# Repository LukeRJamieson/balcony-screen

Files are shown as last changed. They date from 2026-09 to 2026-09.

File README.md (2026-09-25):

# Balcony privacy screen and plant benches

Five free-standing timber plant benches with lattice privacy screens for a
first-floor townhouse balcony. Nothing is fixed to the building.

**Live 3D model:** https://lukerjamieson.github.io/balcony-screen/

This repository is both the website (`index.html` at the root, served by GitHub
Pages) and the complete build project for the **506 mm deep bench** version.

## What's here

| Path | What it is |
|---|---|
| `index.html` | The approval page with the interactive 3D model. Self-contained; GitHub Pages serves it |
| `Build_Guide.pdf`, `Build_Guide.docx` | Printable build guide: parts list, seven steps with a render at each stage, the 900 mm module, finishing |
| `Cutting_Guide.pdf` | Every stock length drawn to scale, with each piece, kerf, offcuts and a tick box per length |
| `BalconyScreenBench/` | The design model: Fusion 360 script (also plain Python), BOM and cut-list spreadsheet, drawing, cutting-guide generator, build README |
| `stl/` | 3D-printable models of the AC unit, figure, BBQ and bistro set, at real size in mm |
| `application/` | Owners corporation works application attachment (Word and PDF) |
| `docs/github-pages.md` | Notes on hosting and updating the page |

Online slide version of the build guide: https://claude.ai/artifact/VX7RYzKuyGwnUHXprddLsv

## The design at a glance

* Five modules, 600 / 600 / 900 / 600 / 600 mm wide, 3340 mm overall
* 1820 mm high, 506 mm deep, bench top at 500, lower shelf at 130
* 90x45 H3 pine frames bolted with M10 cup heads, 90x22 H3 decking boards and rails,
  Lattice Makers economy lattice, merbau cover strips
* About $966 in materials (see the spreadsheet)

## Regenerating from the model

Everything is generated from one model, so it all stays consistent. Edit `Config`
in `BalconyScreenBench/BalconyScreenBench.py`, then:

    cd BalconyScreenBench
    python BalconyScreenBench.py     # dimensions, cut list, stability check
    python export_bom.py             # rebuild the spreadsheet
    python cutting_guide.py          # redraw ../Cutting_Guide.pdf

Run `BalconyScreenBench.py` as a script inside Fusion 360 for the 3D CAD model.

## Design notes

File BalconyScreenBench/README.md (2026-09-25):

# Balcony lattice screen: 5 independent bench modules

Five free-standing modules (600 / 600 / 900 / 600 / 600). Each module is one Lattice Makers economy
(square grid) lattice panel standing 20 mm off the floor, fixed to the back of its own two-tier plant bench.
**Modules are not fixed to each other, the wall or the floor.** Lattice sits 20 mm off the floor; overall height 1820.

## Files

| File | Purpose |
|---|---|
| `BalconyScreenBench.py` | Fusion 360 script **and** the whole parametric layout, in one file |
| `BalconyScreenBench.manifest` | Required by Fusion; must sit next to the .py |
| `export_bom.py` | Regenerates `Balcony_Screen_BOM.xlsx` from the .py (`--csv` for CSV) |
| `Drawings_elevation_section.png` | Dimensioned elevation + section |

## Running in Fusion 360

1. Unzip so you have a folder named exactly **`BalconyScreenBench`** directly containing
   `BalconyScreenBench.py` and `BalconyScreenBench.manifest`.
2. **Utilities > Add-Ins > Scripts and Add-Ins**, click **+** (or *Script or add-in from device*), pick that folder.
3. Select **BalconyScreenBench** > **Run**. Progress bar > a **new design tab** > summary dialog.

The model has one top-level component per module (`Module 1 - 600 wide` ... `Module 5 - 600 wide`).
Each contains a component per timber part, named to match `Cutting_Guide.pdf` - e.g.
`A 1810 - Screen post, rear bench leg - 90x45 pine length #1` is mark A, 1810 mm long, cut from
stock length #1 on the 90x45 pages - plus its own **Fixings** sub-component
(red M10 bolts, blue 10G x 50, green 10G x 65, purple 10G x 100, black packers), so modules can be moved
or hidden individually.

**If it seems to do nothing:** look at the new tab, then check Text Commands and
`BalconyScreenBench_log.txt` in the script folder. No log file = Fusion never ran the script (folder /
manifest issue). A log that stops part way shows which step failed.

Outside Fusion, `python BalconyScreenBench.py` prints dimensions, the cut list and per-module stability.

## Design (per module)

* Width = its lattice panel; row of 5 is 3340 long with 10 mm gaps, centred on the 3550 wall (105 clear each end).
* 601 deep, bench top 500, lower shelf 130, 258 clear under the bench top, 10 mm clear of the wall.
* Section from the wall out: gap > 42x19 merbau strips > lattice > 90x45 post > bench.
* Two 90x45 posts flush with the module ends (1790 long on 10 mm foot packers). The 900 module also
  gets a short mid rear leg and a third frame so the boards don't span too far.
* Each post/leg forms a cross-frame with a front leg and two bearers, bolted 2 x M10 per lap.
* Three 90x45 rails between the posts (bottom, mid, top at 1820). The lattice is screwed through
  wall-side merbau strips into the posts and rails.
* 90x22 H3 decking cut to module width: 5 top boards, 4 shelf boards.
* Lattice modelled as a square grid (25 mm slats at 95 mm centres - visual only; measure your sheets
  and set `lattice_slat_width` / `lattice_slat_pitch`).

## Stability: read this

Each module stands on its own, so it's only as stable as its own weight (~29 kg for a 600, ~40 kg for
the 900) plus the pots on it. Indicative forward-tipping estimate for wind over the wall, assuming the
total pot load is spread evenly along the row and Bunnings' 20% blockout figure (editable on the Summary sheet):

| Total pots across all 5 modules | 600 modules tip at | 900 module tips at |
|---|---|---|
| None | ~92 km/h | ~90 km/h |
| 150 kg | ~114 km/h | ~115 km/h |
| 300 kg | ~132 km/h | ~135 km/h |

If your sheets are denser than 20% (a 25 mm slat on a 95 mm grid is closer to 45%), set
`lattice_solidity` to suit: at 45% the 150 kg case drops to about 95 km/h.

**People are the bigger risk than wind.** An empty 600 module tips forward with a pull of about
6.5 kg (64 N) at the top of the lattice. A child climbing the bench or pulling on the lattice could
bring it down. Keep the pots on them, and treat them as not climbable.

Rough check only (plants' windage ignored), not an engineering assessment.

## Buying and transport (up to 2.7 m)

`max_carry_length = 2700`, so every length is bought whole and all cutting is done at home:
* 90x45 H3 framing and 90x22 H3 decking: all 2.4 m lengths.
* 42x19 merbau screening is only sold in 2.7 m at Bunnings, so you'll be carrying 2.7 m lengths.
  (Set `max_carry_length = 2400` to have the store make one cut per merbau length instead.)

## Before cutting: measure

1. Actual lattice sheet size, **thickness** (model assumes 12 mm), slat width and grid spacing.
2. Clear length between the side balustrades, and the floor fall along the wall (each module may need
   its own packers to sit level, and neighbouring modules should line up).
3. Whether water pools along the wall. The lattice bottom is 20 mm up (`lattice_z0`); raise it if puddles
   are deeper. Overall height = `lattice_z0` + 1800, and the layout check warns above `max_height` (2000).

## Build sequence (repeat for each module)

1. Cut per the **Cutting Plan** sheet; brush cut ends of H3 pine (especially post tops) with end-grain preservative.
2. Build the cross-frames flat, bearers inside the posts. Clamp square, drill 11 mm, bolt.
3. Stand the frames on foot packers at the module width, screw the rear top board first to lock
   spacing, then the other top and shelf boards.
4. Fit the lattice rails with straight 10G x 100 screws (no angled screws anywhere):
   * **Bottom and mid rails** sit on the shelf and bench-top bearers; screw straight down through the
     rail into the bearer at each end.
   * **Top rail**: screw straight through each end post from the module's outside face into the rail end.
   * **900 module bottom rail** is two pieces either side of the mid rear leg. Fit the left piece first and
     screw through the mid leg from its right-hand face into the rail end, *then* fit the right piece,
     which sits on the mid bearer and the right-hand bearer.
   * Use the **Drilling** sheet for exact screw positions; they're placed to miss the frame bolts.
5. Lay the module on its front (bench side down), place the lattice on the posts, fix the vertical
   merbau strips then the horizontals. Pre-drill and countersink all merbau.
6. Stand it up and carry it out. Each module fits through a standard door (the 900 goes through on
   its 506 mm depth). Place 10 mm off the wall, 10 mm from its neighbour, level with packers.

## Notes

* Merbau with galvanised screws can leave dark tannin stains; stainless 10G screws avoid that.
* M10 x 120 bolts protrude ~15 mm past the nut on the 90 mm laps (M10 x 100 is too short).
* Bolt patterns are mirrored on each module's right-hand frames so cup heads on neighbouring modules
  never line up across the 10 mm gap. The model also checks that no two fixings collide.
* The modular version costs more than a single shared-post unit (10 posts and 88 bolts instead of 6 and 56).

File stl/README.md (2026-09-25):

# 3D-printable models

Five STL files, built from the same geometry as the approval page's 3D model.
They are at **real-world size in millimetres** (Z up, flat on the bed, centred),
so scale them in your slicer. Each is a single watertight solid.

| File | Size (L x W x H) | Notes |
|---|---|---|
| `AC_outdoor_unit.stl` | 857 x 333 x 703 mm | Fan guard rings are 14 mm thick at full size |
| `Manikin_1750mm.stl` | 550 x 293 x 1739 mm | Actually 1739 mm tall, as rendered on the page. Rounded feet: use a brim |
| `Weber_kettle_BBQ.stl` | 479 x 479 x 929 mm | Legs are 28 mm diameter at full size; use a brim |
| `Bistro_chair.stl` | 630 x 630 x 835 mm | Print twice |
| `Bistro_table.stl` | 400 x 400 x 380 mm | Prints best upside down on its top |

Small changes made so each prints as one piece (overall sizes unchanged):
the AC fan cowl is a solid ring joined to the guard; the BBQ bowl and lid are
one body, its legs reach the bowl, and the ash catcher and lid handle are
nudged into the body.

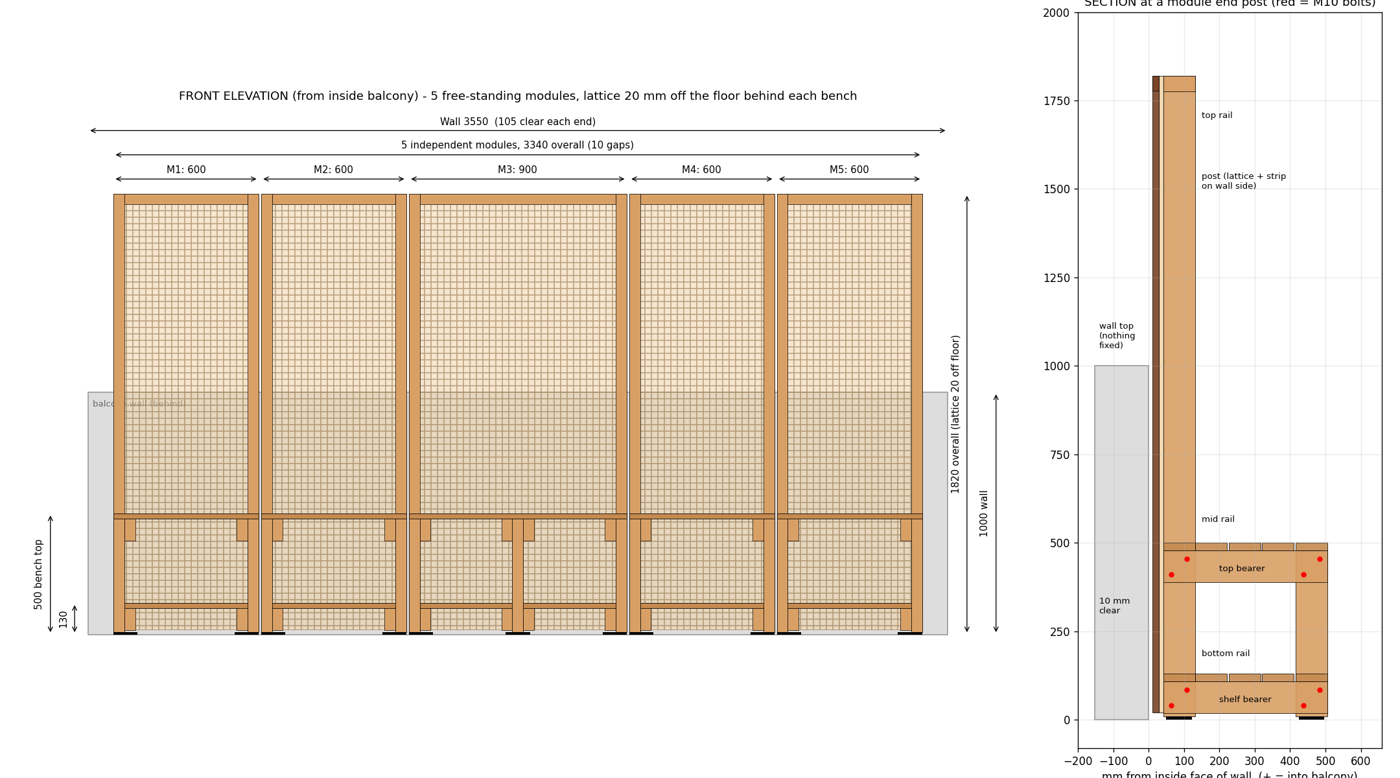
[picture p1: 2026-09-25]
BalconyScreenBench/Drawings_elevation_section.png

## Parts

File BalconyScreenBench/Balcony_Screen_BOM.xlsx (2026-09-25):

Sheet: Summary
Balcony lattice screen - 5 independent bench modules - BOM & cut list
Generated from BalconyScreenBench.py - re-run export_bom.py after changing Config.
Key dimensions (mm)
Wall length (measured) | 3550 | From Luke's measurement
Wall height (approx.) | 1000 | About 1 m - reference only, nothing is fixed to the wall
Lattice panel layout | 600 / 600 / 900 / 600 / 600 | Symmetrical, joints land on posts
Number of independent modules | 5 | One lattice panel + its own bench each; not fixed together
Gap between modules | 10
Overall length of the row | 3340 | Modules + gaps, centred on the wall
Clearance each end | 105 | Wall length minus unit length, halved
Bench top height | 500
Lattice bottom above floor | 20 | Lifted clear of standing water, behind the bench
Maximum height allowed | 2000 | Nothing projects above this
Lower shelf height | 130
Clear height under bench top | 258 | Max pot height on lower shelf
Bench depth from wall | 506
Overall height (top of screen) | 1820
Screen height above wall top | 820
Lattice thickness (assumed) | 12 | NOT listed by Bunnings - measure a sheet
Inputs
Spare allowance - boxed screws | 10% | Extra screws for split/lost ones
Spare allowance - loose items | 5% | Bolts, washers, packers
Estimated total (AUD, inc GST) | $965.94 | Sum of BOM line totals
Stability - INDICATIVE ONLY (not an engineering check)
Total pot + soil load, all modules (kg) | 150 | Edit: weigh or estimate your pots
Module checked | M1 (600 wide) | Least stable module (modules are independent)
Module share of pots (by width) | 18.2% | Assumes pots spread evenly along the row
Unit self weight (kg) | 25.9 | This module only, from timber volumes and densities
Self-weight lever arm to front edge (m) | 0.324 | Horizontal distance, centre of mass to front of legs
Pot lever arm to front edge (m) | 0.188 | Pots assumed centred on bench top
Drag coefficient on solid area | 1.2 | Edit if you have better data
Solid frontal area above wall top (m2) | 0.171 | 20% of lattice + cover strips, above the wall (wall shelters the rest)
Height of wind load centroid (m) | 1.449 | Above deck
Resisting moment (N.m) | 132.6151116 | (self weight x lever + pot share x lever) x 9.81
Estimated tipping gust (km/h) | 98.15230707 | Wind over the wall pushing the unit into the balcony
Legend
Blue text on yellow = input you can edit
Prices: Bunnings online price checked 16 Sep 2026. Packs (e.g. 25-pack bolts) are often cheaper per unit.

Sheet: BOM
Item | Category | Bunnings product | Buy unit | Qty needed | Pack size | Qty to buy | Unit price (AUD) | Line total (AUD) | Link | Notes | Alt supplier | Alt buy unit | Alt pack size | Alt qty to buy | Alt unit price (AUD) | Alt line total (AUD) | Alt link | Cheaper by (AUD)
1 | Timber | 90 x 45mm Outdoor Framing H3 Treated Pine (MGP10) | 2.4 m length | 17 | 1 | 17 | $18.50 | $314.50 | Bunnings (https://www.bunnings.com.au/90-x-45mm-outdoor-framing-mgp10-h3-treated-pine-1-8m-2-4m_p8032172) | Posts, bench frames, lattice rails (bottom / mid / top). Trade counter - price on application. Quote the whole timber list at once | Bowens Croydon / Mount Evelyn, Bayswater Mitre 10 | 2.4 m length |  |  |  |  | Supplier (https://bowens.com.au/stores/croydon)
2 | Timber | 90 x 22mm Decking H3 Treated Pine | 2.4 m length | 14 | 1 | 14 | $9.58 | $134.12 | Bunnings (https://www.bunnings.com.au/90-x-22mm-decking-h3-treated-pine-2-4m_p8032583) | Per module: 5 top + 4 shelf boards cut to module width. Trade counter - price on application | Bowens Croydon / Mount Evelyn, Bayswater Mitre 10 | 2.4 m length |  |  |  |  | Supplier (https://bowens.com.au/stores/croydon)
3 | Timber | SpecRite 42 x 19mm Merbau Pre-Oiled Solid Screening | 2.7 m length | 10 | 1 | 10 | $9.00 | $90.00 | Bunnings (https://www.bunnings.com.au/products/building-hardware/fencing/timber-fencing) | Cover strips on the wall side (hardwood - pre-drill). Only sold in 2.7 m: ask Bunnings to cut each length at the position on the Cutting Plan sheet. Merbau screening lengths vary by merchant - check stocked lengths | Bowens Croydon / Mount Evelyn, Bayswater Mitre 10 | length |  |  |  |  | Supplier (https://bowens.com.au/stores/croydon)
4 | Lattice | Lattice Makers 1800 x 600mm Economy Lattice | sheet | 4 | 1 | 4 | $19.99 | $79.96 | Bunnings (https://www.bunnings.com.au/lattice-makers-1800-x-600mm-economy-lattice_p0920946) | 20% blockout, pine; no cutting needed
5 | Lattice | Lattice Makers 1800 x 900mm Economy Lattice | sheet | 1 | 1 | 1 | $27.89 | $27.89 | Bunnings (https://www.bunnings.com.au/lattice-makers-1800-x-900mm-economy-lattice_p0920950) | 20% blockout, pine; no cutting needed
6 | Fixings | ZENITH M10 x 120mm Hot Dip Galvanised Cup Head Bolts & Nuts - Each | each | 80 | 1 | 84 | $1.74 | $146.16 | Bunnings (https://www.bunnings.com.au/zenith-m10-x-120mm-hot-dip-galvanised-cup-head-bolts-nuts-each_p2443953) | Frame lap joints, 2 per joint. Far cheaper by the box - see alt supply. Also Scrooz: trade box of 25 at $25.39 ($1.02 ea), free shipping over $99 | The Fastener Factory (Clayton / online) | box of 50 | 50 | 2 | $38.09 | $76.18 | Supplier (https://www.thefastenerfactory.com.au/m10-x-120mm-50pc-cup-head-bolt-nut-hot-dip-galvanised-as1390-class-4-6-uts) | $69.98
7 | Fixings | ZENITH M10 x 150mm Hot Dip Galvanised Cup Head Bolts & Nuts - Each | each | 8 | 1 | 9 | $1.94 | $17.46 | Bunnings (https://www.bunnings.com.au/zenith-m10-x-150mm-hot-dip-galvanised-cup-head-bolts-nuts-each_p2443987) | The 900 module's middle frame only: four joints of 45 + 45 + 45
8 | Fixings | ZENITH M10 Hot Dip Galvanised Flat Round Washers - Each | each | 88 | 1 | 93 | $0.30 | $27.90 | Bunnings (https://www.bunnings.com.au/zenith-m10-hot-dip-galvanised-flat-round-washers-each_p2442070) | One under each nut, both bolt lengths. One box covers the job several times over; cheaper than 93 loose | The Fastener Factory (Clayton / online) | box of 500 | 500 | 1 | $22.87 | $22.87 | Supplier (https://www.thefastenerfactory.com.au/m10-galvanised-flat-washers-10mm-x-22-5-x-2-0-500pc) | $5.03
9 | Fixings | Zenith 10-8 x 50mm Galvanised Countersunk Rib Head Timber Screws - 50 Pack | pack | 192 | 50 | 5 | $8.79 | $43.95 | Bunnings (https://www.bunnings.com.au/search/products?q=galvanised+timber+screws) | Deck boards to bearers, 2 per board per bearer
10 | Fixings | Zenith 10-8 x 65mm Galvanised Countersunk Rib Head Timber Screws - 50 Pack | pack | 86 | 50 | 2 | $10.90 | $21.80 | Bunnings (https://www.bunnings.com.au/products/building-hardware/fasteners-fixings/screws/treated-pine-screws) | Cover strips through lattice into posts and rails @ ~300 c/c
11 | Fixings | Zenith 10-8 x 100mm Galvanised Countersunk Rib Head Timber Screws - 50 Pack | pack | 64 | 50 | 2 | $14.90 | $29.80 | Bunnings (https://www.bunnings.com.au/zenith-10-8-x-100mm-galvanised-countersunk-rib-head-timber-screws-50-pack_p2420881) | Lattice rails: down into bearers or through the end posts, 2 per rail end. Buy the 50-pack, not 8-packs
12 | Fixings | Titan 10 x 72 x 100mm Black Shim Packing | each | 22 | 1 | 24 | $1.35 | $32.40 | Bunnings (https://www.bunnings.com.au/products/building-hardware/fasteners-fixings) | Feet under every leg (confirm sold each). Ask for plastic packers by the bag rather than singly | Trade counter (Bowens / Mitre 10) | bag |  |  |  |  | Supplier (https://bowens.com.au/stores/croydon)
 |  |  |  |  |  |  | TOTAL | $965.94 |  |  |  |  |  | TOTAL, cheaper option per row |  | $890.93 | Saving | $75.01
 |  |  |  |  |  |  |  |  |  |  | Rows with an alt price are priced both ways; blank alt prices are trade counters that quote on request.
 |  | Not included: exterior oil/stain, drill bits (11 mm auger, 3.5 mm pilot, countersink), and any owners corporation fees.

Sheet: Cut List
Mark | Description | Material | Section | Cut length (mm) | Qty | Total length (m) | Part IDs
A | Screen post / rear bench leg | 90 x 45mm Outdoor Framing H3 Treated Pine (MGP10) | 90x45 | 1810 | 10 | 18.10 | M1-POST-1 M1-POST-2 M2-POST-1 M2-POST-2 M3-POST-1 M3-POST-2 M4-POST-1 M4-POST-2 M5-POST-1 M5-POST-2
B | Lattice rail (top) | 90 x 45mm Outdoor Framing H3 Treated Pine (MGP10) | 90x45 | 810 | 1 | 0.81 | M3-RAILTOP-4
C | Lattice rail (top) | 90 x 45mm Outdoor Framing H3 Treated Pine (MGP10) | 90x45 | 510 | 4 | 2.04 | M1-RAILTOP-3 M2-RAILTOP-3 M4-RAILTOP-3 M5-RAILTOP-3
D | Front bench leg; Rear bench leg (mid frame) | 90 x 45mm Outdoor Framing H3 Treated Pine (MGP10) | 90x45 | 468 | 12 | 5.62 | M1-FLEG-1 M1-FLEG-2 M2-FLEG-1 M2-FLEG-2 M3-FLEG-1 M3-RLEG-1 M3-FLEG-2 M3-FLEG-3 M4-FLEG-1 M4-FLEG-2 M5-FLEG-1 M5-FLEG-2
E | Bench top bearer; Lower shelf bearer | 90 x 45mm Outdoor Framing H3 Treated Pine (MGP10) | 90x45 | 465 | 24 | 11.16 | M1-TBEAR-1 M1-LBEAR-1 M1-TBEAR-2 M1-LBEAR-2 M2-TBEAR-1 M2-LBEAR-1 M2-TBEAR-2 M2-LBEAR-2 M3-TBEAR-1 M3-LBEAR-1 M3-TBEAR-2 M3-LBEAR-2 M3-TBEAR-2B M3-LBEAR-2B M3-TBEAR-3 M3-LBEAR-3 M4-TBEAR-1 M4-LBEAR-1 M4-TBEAR-2 M4-LBEAR-2 M5-TBEAR-1 M5-LBEAR-1 M5-TBEAR-2 M5-LBEAR-2
F | Bench top board; Lower shelf board | 90 x 22mm Decking H3 Treated Pine | 90x22 | 900 | 7 | 6.30 | M3-TOP-1 M3-TOP-2 M3-TOP-3 M3-TOP-4 M3-SHELF-1 M3-SHELF-2 M3-SHELF-3
G | Lattice rail (mid) | 90 x 22mm Decking H3 Treated Pine | 90x22 | 810 | 1 | 0.81 | M3-RAILMID-3
H | Bench top board; Lower shelf board | 90 x 22mm Decking H3 Treated Pine | 90x22 | 600 | 28 | 16.80 | M1-TOP-1 M1-TOP-2 M1-TOP-3 M1-TOP-4 M1-SHELF-1 M1-SHELF-2 M1-SHELF-3 M2-TOP-1 M2-TOP-2 M2-TOP-3 M2-TOP-4 M2-SHELF-1 M2-SHELF-2 M2-SHELF-3 M4-TOP-1 M4-TOP-2 M4-TOP-3 M4-TOP-4 M4-SHELF-1 M4-SHELF-2 M4-SHELF-3 M5-TOP-1 M5-TOP-2 M5-TOP-3 M5-TOP-4 M5-SHELF-1 M5-SHELF-2 M5-SHELF-3
I | Lower shelf board; Lattice rail (bot); Lattice rail (mid) | 90 x 22mm Decking H3 Treated Pine | 90x22 | 510 | 12 | 6.12 | M1-SHELF-4a M1-RAILBOT-1 M1-RAILMID-2 M2-SHELF-4a M2-RAILBOT-1 M2-RAILMID-2 M4-SHELF-4a M4-RAILBOT-1 M4-RAILMID-2 M5-SHELF-4a M5-RAILBOT-1 M5-RAILMID-2
J | Lower shelf board; Lattice rail (bot) | 90 x 22mm Decking H3 Treated Pine | 90x22 | 382.5 | 4 | 1.53 | M3-SHELF-4a M3-SHELF-4b M3-RAILBOT-1 M3-RAILBOT-2
K | Vertical cover strip (wall side) | SpecRite 42 x 19mm Merbau Pre-Oiled Solid Screening | 42x19 | 1800 | 10 | 18.00 | M1-VSTRIP-1 M1-VSTRIP-2 M2-VSTRIP-1 M2-VSTRIP-2 M3-VSTRIP-1 M3-VSTRIP-2 M4-VSTRIP-1 M4-VSTRIP-2 M5-VSTRIP-1 M5-VSTRIP-2
L | Horizontal cover strip (top, wall side) | SpecRite 42 x 19mm Merbau Pre-Oiled Solid Screening | 42x19 | 816 | 1 | 0.82 | M3-HSTRIP-TOP
M | Horizontal cover strip (top, wall side) | SpecRite 42 x 19mm Merbau Pre-Oiled Solid Screening | 42x19 | 516 | 4 | 2.06 | M1-HSTRIP-TOP M2-HSTRIP-TOP M4-HSTRIP-TOP M5-HSTRIP-TOP
Lengths are finished sizes. Cut 90x45 and decking square; pre-drill all merbau (hardwood).

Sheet: Cutting Plan
Stock # | Material key | Material | Stock length (mm) | Pieces (mark: length) | No. pieces | Pieces total (mm) | Kerf + trim (mm) | Offcut (mm) | Ask store to cut at (mm from one end)
T90x45-1 | T90x45 | 90 x 45mm Outdoor Framing H3 Treated Pine (MGP10) | 2400 | A: 1810 | C: 510 | 2 | 2320 | 16 | 64
T90x45-2 | T90x45 | 90 x 45mm Outdoor Framing H3 Treated Pine (MGP10) | 2400 | A: 1810 | C: 510 | 2 | 2320 | 16 | 64
T90x45-3 | T90x45 | 90 x 45mm Outdoor Framing H3 Treated Pine (MGP10) | 2400 | A: 1810 | C: 510 | 2 | 2320 | 16 | 64
T90x45-4 | T90x45 | 90 x 45mm Outdoor Framing H3 Treated Pine (MGP10) | 2400 | A: 1810 | C: 510 | 2 | 2320 | 16 | 64
T90x45-5 | T90x45 | 90 x 45mm Outdoor Framing H3 Treated Pine (MGP10) | 2400 | A: 1810 | D: 468 | 2 | 2278 | 16 | 106
T90x45-6 | T90x45 | 90 x 45mm Outdoor Framing H3 Treated Pine (MGP10) | 2400 | A: 1810 | D: 468 | 2 | 2278 | 16 | 106
T90x45-7 | T90x45 | 90 x 45mm Outdoor Framing H3 Treated Pine (MGP10) | 2400 | A: 1810 | D: 468 | 2 | 2278 | 16 | 106
T90x45-8 | T90x45 | 90 x 45mm Outdoor Framing H3 Treated Pine (MGP10) | 2400 | A: 1810 | D: 468 | 2 | 2278 | 16 | 106
T90x45-9 | T90x45 | 90 x 45mm Outdoor Framing H3 Treated Pine (MGP10) | 2400 | A: 1810 | D: 468 | 2 | 2278 | 16 | 106
T90x45-10 | T90x45 | 90 x 45mm Outdoor Framing H3 Treated Pine (MGP10) | 2400 | A: 1810 | D: 468 | 2 | 2278 | 16 | 106
T90x45-11 | T90x45 | 90 x 45mm Outdoor Framing H3 Treated Pine (MGP10) | 2400 | B: 810 | D: 468 | D: 468 | D: 468 | 4 | 2214 | 22 | 164
T90x45-12 | T90x45 | 90 x 45mm Outdoor Framing H3 Treated Pine (MGP10) | 2400 | D: 468 | D: 468 | D: 468 | E: 465 | E: 465 | 5 | 2334 | 25 | 41
T90x45-13 | T90x45 | 90 x 45mm Outdoor Framing H3 Treated Pine (MGP10) | 2400 | E: 465 | E: 465 | E: 465 | E: 465 | E: 465 | 5 | 2325 | 25 | 50
T90x45-14 | T90x45 | 90 x 45mm Outdoor Framing H3 Treated Pine (MGP10) | 2400 | E: 465 | E: 465 | E: 465 | E: 465 | E: 465 | 5 | 2325 | 25 | 50
T90x45-15 | T90x45 | 90 x 45mm Outdoor Framing H3 Treated Pine (MGP10) | 2400 | E: 465 | E: 465 | E: 465 | E: 465 | E: 465 | 5 | 2325 | 25 | 50
T90x45-16 | T90x45 | 90 x 45mm Outdoor Framing H3 Treated Pine (MGP10) | 2400 | E: 465 | E: 465 | E: 465 | E: 465 | E: 465 | 5 | 2325 | 25 | 50
T90x45-17 | T90x45 | 90 x 45mm Outdoor Framing H3 Treated Pine (MGP10) | 2400 | E: 465 | E: 465 | 2 | 930 | 16 | 1454
D90x22-1 | D90x22 | 90 x 22mm Decking H3 Treated Pine | 2400 | F: 900 | F: 900 | I: 510 | 3 | 2310 | 19 | 71
D90x22-2 | D90x22 | 90 x 22mm Decking H3 Treated Pine | 2400 | F: 900 | F: 900 | I: 510 | 3 | 2310 | 19 | 71
D90x22-3 | D90x22 | 90 x 22mm Decking H3 Treated Pine | 2400 | F: 900 | F: 900 | I: 510 | 3 | 2310 | 19 | 71
D90x22-4 | D90x22 | 90 x 22mm Decking H3 Treated Pine | 2400 | F: 900 | G: 810 | H: 600 | 3 | 2310 | 19 | 71
D90x22-5 | D90x22 | 90 x 22mm Decking H3 Treated Pine | 2400 | H: 600 | H: 600 | H: 600 | I: 510 | 4 | 2310 | 22 | 68
D90x22-6 | D90x22 | 90 x 22mm Decking H3 Treated Pine | 2400 | H: 600 | H: 600 | H: 600 | I: 510 | 4 | 2310 | 22 | 68
D90x22-7 | D90x22 | 90 x 22mm Decking H3 Treated Pine | 2400 | H: 600 | H: 600 | H: 600 | I: 510 | 4 | 2310 | 22 | 68
D90x22-8 | D90x22 | 90 x 22mm Decking H3 Treated Pine | 2400 | H: 600 | H: 600 | H: 600 | I: 510 | 4 | 2310 | 22 | 68
D90x22-9 | D90x22 | 90 x 22mm Decking H3 Treated Pine | 2400 | H: 600 | H: 600 | H: 600 | I: 510 | 4 | 2310 | 22 | 68
D90x22-10 | D90x22 | 90 x 22mm Decking H3 Treated Pine | 2400 | H: 600 | H: 600 | H: 600 | I: 510 | 4 | 2310 | 22 | 68
D90x22-11 | D90x22 | 90 x 22mm Decking H3 Treated Pine | 2400 | H: 600 | H: 600 | H: 600 | I: 510 | 4 | 2310 | 22 | 68
D90x22-12 | D90x22 | 90 x 22mm Decking H3 Treated Pine | 2400 | H: 600 | H: 600 | H: 600 | I: 510 | 4 | 2310 | 22 | 68
D90x22-13 | D90x22 | 90 x 22mm Decking H3 Treated Pine | 2400 | H: 600 | H: 600 | H: 600 | I: 510 | 4 | 2310 | 22 | 68
D90x22-14 | D90x22 | 90 x 22mm Decking H3 Treated Pine | 2400 | J: 382.5 | J: 382.5 | J: 382.5 | J: 382.5 | 4 | 1530 | 22 | 848
M42x19-1 | M42x19 | SpecRite 42 x 19mm Merbau Pre-Oiled Solid Screening | 2700 | K: 1800 | L: 816 | 2 | 2616 | 16 | 68
M42x19-2 | M42x19 | SpecRite 42 x 19mm Merbau Pre-Oiled Solid Screening | 2700 | K: 1800 | M: 516 | 2 | 2316 | 16 | 368
M42x19-3 | M42x19 | SpecRite 42 x 19mm Merbau Pre-Oiled Solid Screening | 2700 | K: 1800 | M: 516 | 2 | 2316 | 16 | 368
M42x19-4 | M42x19 | SpecRite 42 x 19mm Merbau Pre-Oiled Solid Screening | 2700 | K: 1800 | M: 516 | 2 | 2316 | 16 | 368
M42x19-5 | M42x19 | SpecRite 42 x 19mm Merbau Pre-Oiled Solid Screening | 2700 | K: 1800 | M: 516 | 2 | 2316 | 16 | 368
M42x19-6 | M42x19 | SpecRite 42 x 19mm Merbau Pre-Oiled Solid Screening | 2700 | K: 1800 | 1 | 1800 | 13 | 887
M42x19-7 | M42x19 | SpecRite 42 x 19mm Merbau Pre-Oiled Solid Screening | 2700 | K: 1800 | 1 | 1800 | 13 | 887
M42x19-8 | M42x19 | SpecRite 42 x 19mm Merbau Pre-Oiled Solid Screening | 2700 | K: 1800 | 1 | 1800 | 13 | 887
M42x19-9 | M42x19 | SpecRite 42 x 19mm Merbau Pre-Oiled Solid Screening | 2700 | K: 1800 | 1 | 1800 | 13 | 887
M42x19-10 | M42x19 | SpecRite 42 x 19mm Merbau Pre-Oiled Solid Screening | 2700 | K: 1800 | 1 | 1800 | 13 | 887
Assumes 3 mm saw kerf per cut and 10 mm end trim per length. All lengths are bought whole and cut at home; no in-store cuts.
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

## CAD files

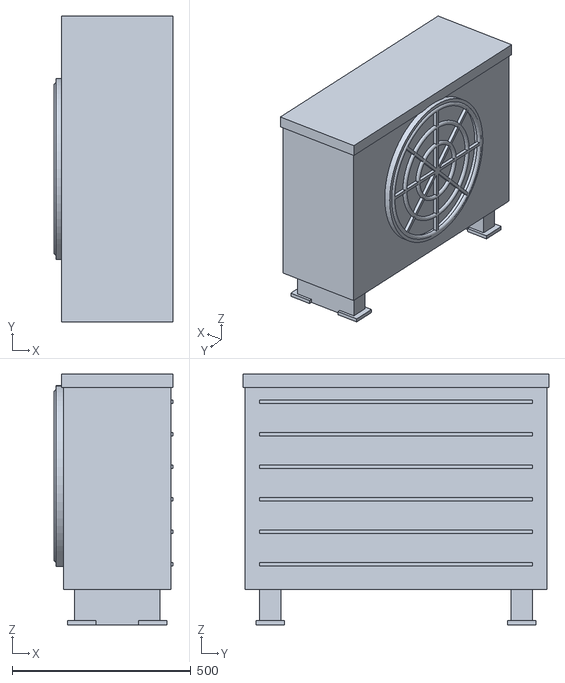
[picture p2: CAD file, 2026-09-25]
stl/AC_outdoor_unit.stl
333.0 x 857.0 x 703.0

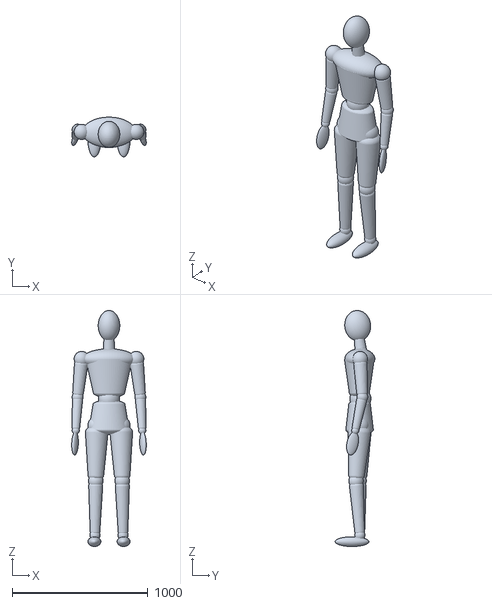
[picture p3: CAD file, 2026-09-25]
stl/Manikin_1750mm.stl
550.4 x 292.8 x 1739.1

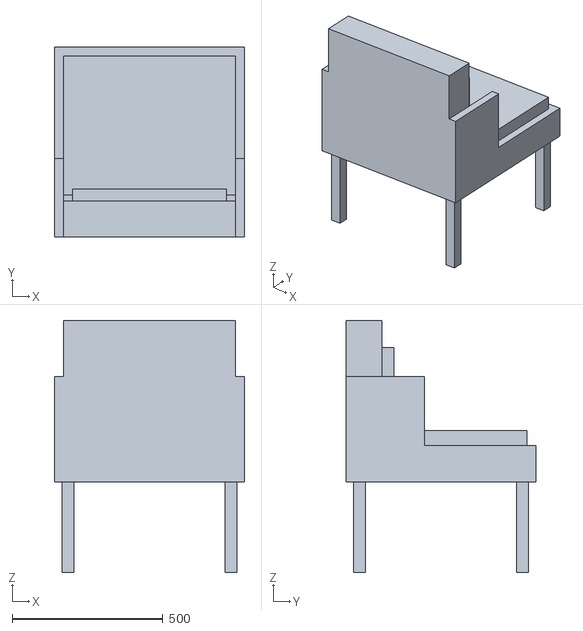
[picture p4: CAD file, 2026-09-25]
stl/Bistro_chair.stl
630.0 x 630.0 x 835.0

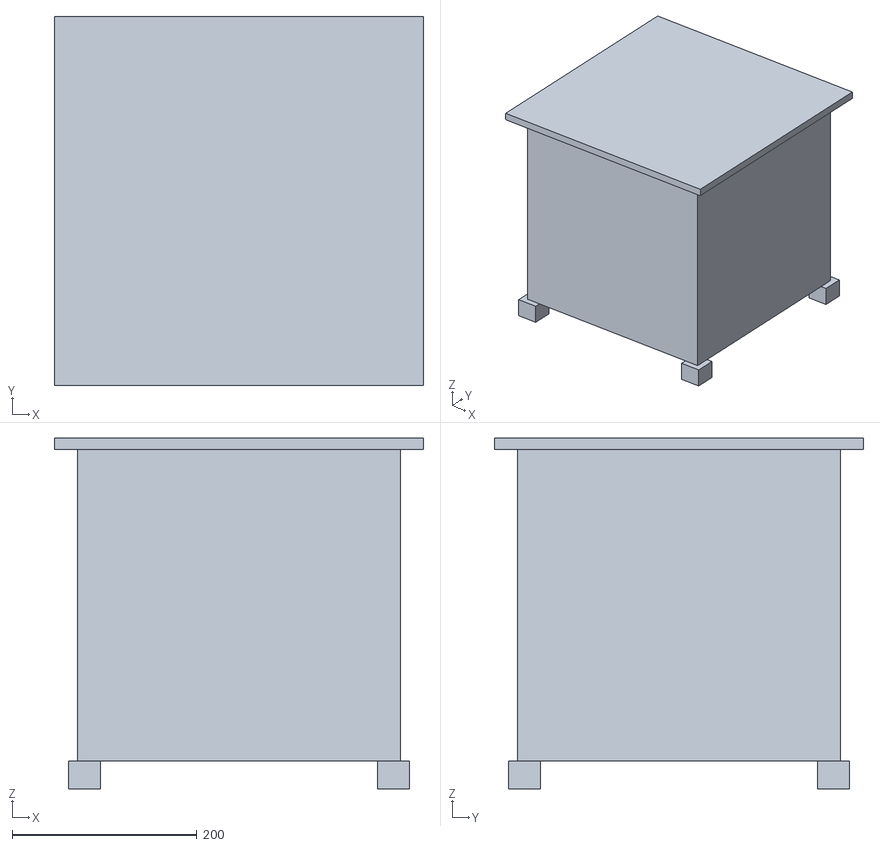
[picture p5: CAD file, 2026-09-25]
stl/Bistro_table.stl
400.0 x 400.0 x 380.0

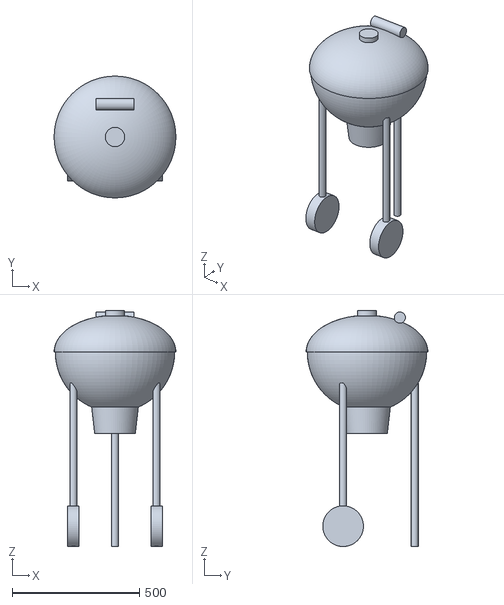
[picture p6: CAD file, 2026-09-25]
stl/Weber_kettle_BBQ.stl
479.4 x 479.4 x 929.0

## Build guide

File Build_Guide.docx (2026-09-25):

BALCONY SCREEN BUILD GUIDE

506 mm bench · five free-standing modules · 1820 mm high

Five modules: four 600 mm wide and one 900 mm in the centre. Each is a two-tier plant bench with a lattice panel fixed to its back. Build one at a time; roughly 25 to 35 hours in total, 6 to 8 hours for the first module and 3 to 4 for each one after.

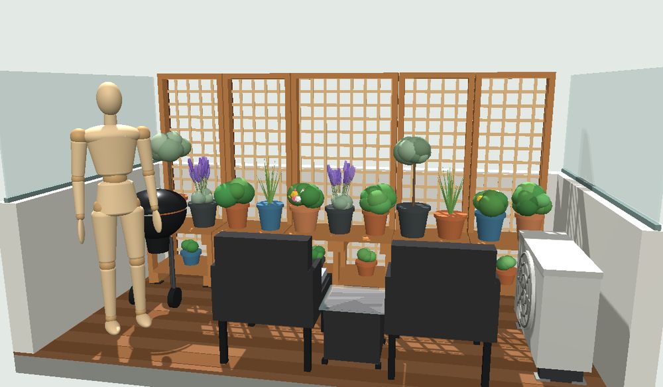
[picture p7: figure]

Before you start

- Tools: mitre saw, drill and impact driver, 11 mm auger or spade bit, 3.5 mm pilot bit and countersink, 17 mm spanner or socket, four clamps, square, tape.
- Consumables: end-grain preservative, pigmented decking oil, spare driver bits.
- Safety: glasses, ear protection, dust mask. Sweep up treated pine dust; do not burn offcuts.

Parts for one 600 module (506 mm bench)

Qty | Length | Material | Part
2 | 1810 | 90x45 H3 | Posts
2 | 468 | 90x45 H3 | Front legs
4 | 465 | 90x45 H3 | Bearers, two per frame
1 | 510 | 90x45 H3 | Top rail
2 | 510 | 90x22 H3 | Bottom and mid rails, both flush
1 | 510 | 90x22 H3 | Front shelf piece, between the legs
7 | 600 | 90x22 H3 | Boards: 4 top, 3 full-width shelf
2 | 1800 | 42x19 merbau | Vertical cover strips
1 | 516 | 42x19 merbau | Top cover strip
1 | 1800 x 600 | Lattice | Screen panel

Fixings per module: 16 M10x120 bolts with washers, 32 x 50 mm screws, 17 x 65 mm screws, 12 x 100 mm screws, 4 plastic foot packers.

01 Cut and seal

- Work through the Cutting Plan one stock length at a time; use a stop block for the repeats.
- Pencil the mark letter on every piece as it comes off the saw.
- Seal every cut end, especially the post tops.


02 Drill the bolt holes

- 11 mm holes, not 10 mm.
- Two bolts per joint on the diagonal, each 22.5 mm in from both edges of the lap.
- Clamp both pieces and drill through together; back the exit side with an offcut.

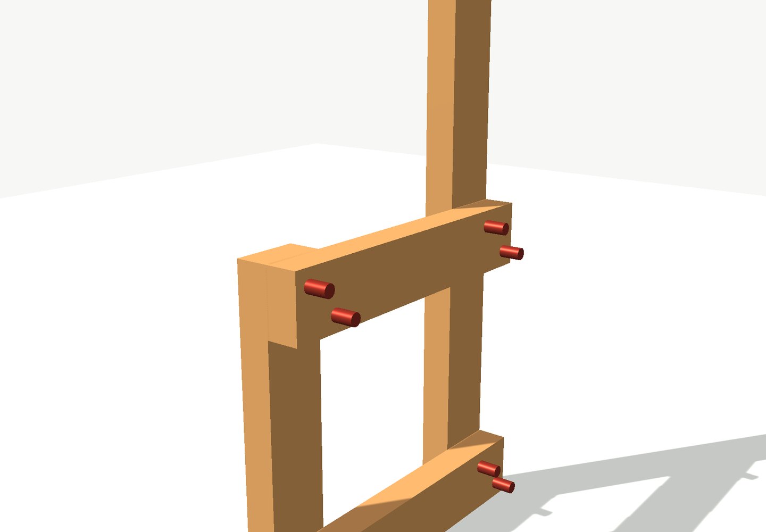
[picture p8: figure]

03 Bolt up the cross-frames

- One frame is a post, a front leg and two bearers.
- 600 modules take two frames. The 900 module takes three: its middle frame is built now too, using a 468 mm rear leg in place of the post, and a second bearer at each level. See the 900 mm section for that frame.
- Bearers lap on the side facing the middle of the module.
- Shelf bearer top at 108, bench bearer top at 478, measured from the bottom of the post or rear leg.
- Nip the bolts up, check the diagonals match, then tighten.

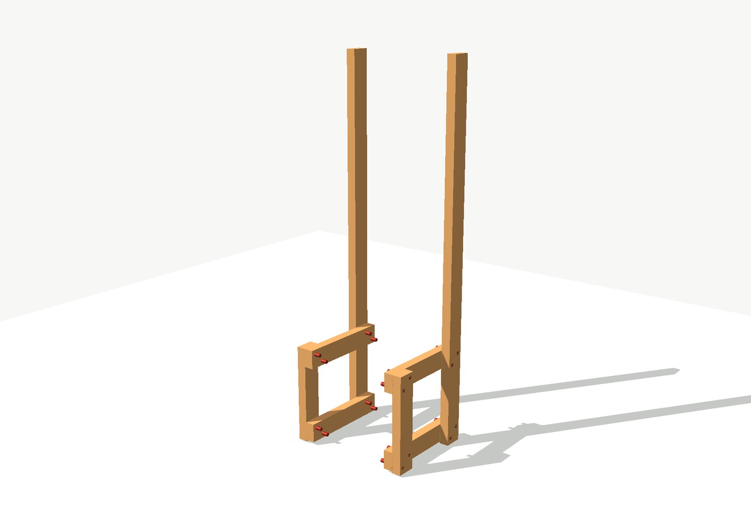
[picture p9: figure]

04 Fit the boards

- Rear top board first: it sets the frame spacing.
- Then the rest of the 4 top boards with 5 mm gaps, and 4 shelf boards.
- The front shelf board is cut to fit between the legs, so the shelf reaches the front.
- Two screws per board at every bearer it crosses; 32 screws in all. Pre-drill within 50 mm of a board end.

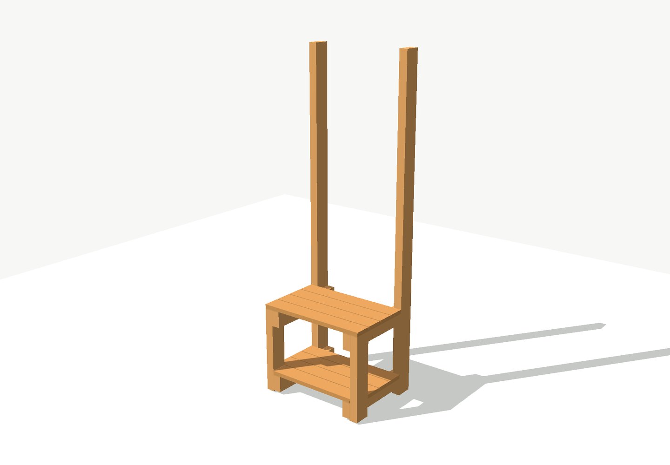
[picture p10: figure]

05 Three rails between the posts

- Bottom rail, 90x22, sits on the shelf bearers and finishes flush at 130.
- Mid rail, 90x22, sits on the bench bearers and finishes flush at 500.
- Top rail, 90x45, is flush with the post tops at 1820.
- Screw straight down into the bearers, or straight through the posts from outside. No angled screws.

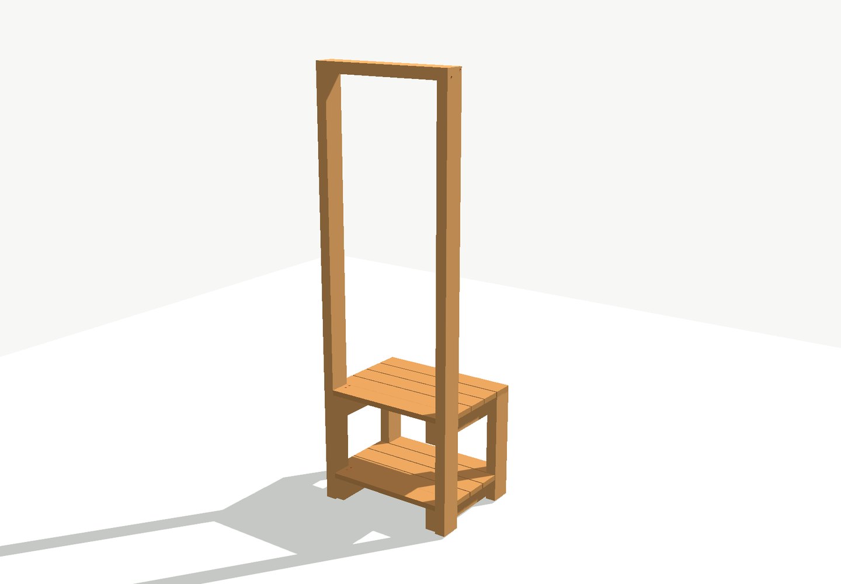
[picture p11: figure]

06 Lattice and cover strips

- Lay the module on its front, bench side down.
- Lattice on the posts, 20 mm up from the floor line.
- A vertical strip over each post and one along the top: the lattice is clamped around its perimeter. The rails behind carry no strips.
- Screws at roughly 300 mm centres, 17 in all. Pre-drill and countersink every merbau screw.

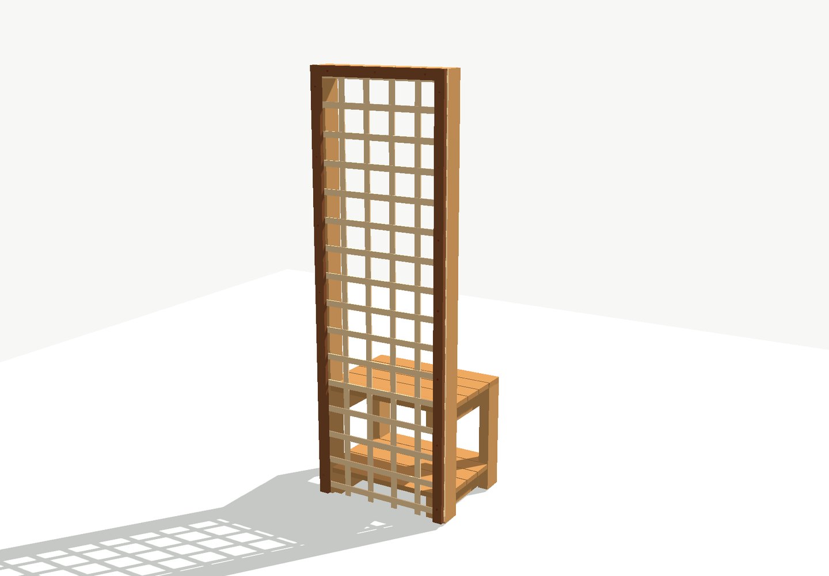
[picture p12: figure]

07 Carry out, pack and place

- 26 kg for a 600 module; it fits through a doorway upright.
- A plastic packer under each of the four legs.
- 10 mm clear of the wall, 10 mm to its neighbour, then level it across and front to back.
- Load the pots on before you leave it: empty, a module tips forward with about 4.6 kg of pull at the top.

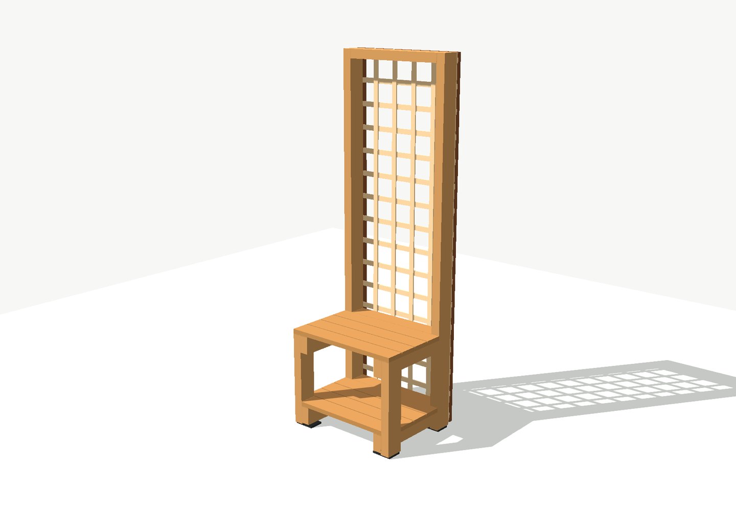
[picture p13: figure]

The 900 mm centre module

- Three cross-frames instead of two.
- The middle frame is a full leg pair: a rear leg and a front leg, both 468 long to 478, so the back of the bench top is carried at mid-span. The rear leg stops at bench height so it does not foul the lattice.
- Second bearers on the far side of the middle frame at both levels, carrying the boards either side of it.
- Those four joints bolt through 45 + 45 + 45, so they take M10x150 bolts.
- 16 x M10x120 plus 8 x M10x150, and 64 fifty-mm screws.
- The bottom rail is two 382 mm pieces. Fit the left piece and screw through the middle leg into its end first, then the right piece. 37 kg before pots.

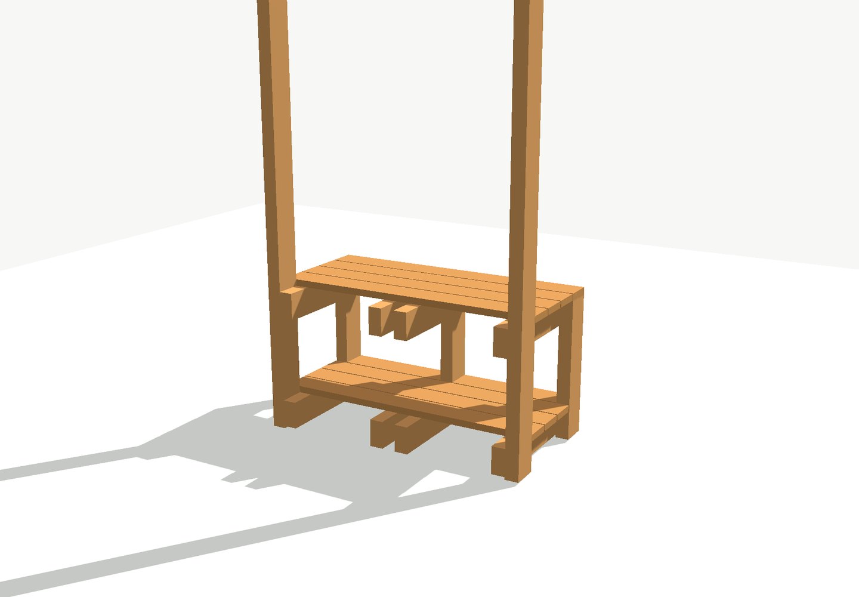
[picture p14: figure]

Seen from the wall side: the middle frame's rear leg runs to the underside of the bench top.

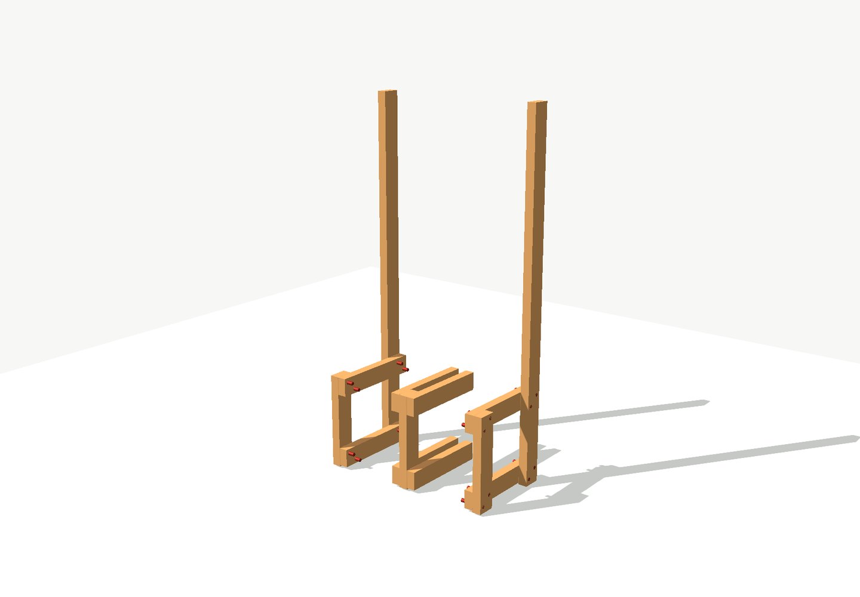
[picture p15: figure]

The same module from the front, with all three frames standing.

Finishing and first-year care

- H3 treatment handles rot; oil is for looks and to slow surface checking. Use a pigmented oil, since clear gives almost no UV protection.
- Coat parts before assembly where you can, and spray or dip the lattice rather than brushing it.
- Re-tighten every M10 nut after about a month, then check each spring.
- Keep the pots on: they are what hold the modules down. Keep children off; the lattice is not a barrier.

Slide version of this guide: https://claude.ai/artifact/VX7RYzKuyGwnUHXprddLsv

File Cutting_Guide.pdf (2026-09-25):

# Cutting guide: balcony screen benches

4-board bench, 41 lengths of timber, every piece drawn to scale on the pages that follow.

# What to buy

# 17 x 90 x 45 H3 treated pine, 2.4 m

# 14 x 90 x 22 H3 decking, 2.4 m

# 10 x 42 x 19 merbau screening, 2.7 m

# Pieces by mark

## A 10 x 1810 mm 90 x 45

Screen post / rear bench leg

## B 1 x 810 mm 90 x 45

Lattice rail (top)

## C 4 x 510 mm 90 x 45

Lattice rail (top)

## D 12 x 468 mm 90 x 45

Front bench leg / Rear bench leg (mid frame)

## E 24 x 465 mm 90 x 45

Bench top bearer / Lower shelf bearer

## F 7 x 900 mm 90 x 22

Bench top board / Lower shelf board

## G 1 x 810 mm 90 x 22

Lattice rail (mid)

## H 28 x 600 mm 90 x 22

Bench top board / Lower shelf board

## I 12 x 510 mm 90 x 22

Lower shelf board / Lattice rail (bot) / Lattice rail (mid)

## J 4 x 382 mm 90 x 22

Lower shelf board / Lattice rail (bot)

## K 10 x 1800 mm 42 x 19

Vertical cover strip (wall side)

## L 1 x 816 mm 42 x 19

Horizontal cover strip (top, wall side)

## M 4 x 516 mm 42 x 19

Horizontal cover strip (top, wall side)

Tip: set a stop block for the repeat lengths (bearers, legs, boards) and cut all of one mark in a batch. Seal every cut end as you go.

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

K 1800
M1 · Vertical cover strip (wall side)

L 816
M3 · Horizontal cover strip (top, wall side)

offcut 76

#1

2.7 m

K 1800
M1 · Vertical cover strip (wall side)

M 516
M1 | · | Horizontal cover strip (top, wall side)
#2 | offcut 376

2.7 m

K 1800
M2 · Vertical cover strip (wall side)

M 516
M2 | · | Horizontal cover strip (top, wall side)
#3 | offcut 376

2.7 m

K 1800
M2 · Vertical cover strip (wall side)

M 516
M4 | · | Horizontal cover strip (top, wall side)
#4 | offcut 376

2.7 m

K 1800
M3 · Vertical cover strip (wall side)

M 516
M5 | · | Horizontal cover strip (top, wall side)
#5 | offcut 376

2.7 m

# 42 x 19 merbau screening: 10 x 2.7 m (page 1 of 2)

Measure from the squared end. 5 mm squaring trim at the start, 3 mm saw kerf between pieces. Cut the longest piece first and pencil its mark on it.

K 1800 mm | L 816 mm | M 516 mm

K 1800
M3 · Vertical cover strip (wall side)
#6 | offcut 895

2.7 m

K 1800
M4 · Vertical cover strip (wall side)
#7 | offcut 895

2.7 m

K 1800
M4 · Vertical cover strip (wall side)
#8 | offcut 895

2.7 m

K 1800
M5 · Vertical cover strip (wall side)
#9 | offcut 895

2.7 m

K 1800
M5 · Vertical cover strip (wall side)
#10 | offcut 895

2.7 m

# 42 x 19 merbau screening: 10 x 2.7 m (page 2 of 2)

Measure from the squared end. 5 mm squaring trim at the start, 3 mm saw kerf between pieces. Cut the longest piece first and pencil its mark on it.

K 1800 mm
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

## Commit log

2026-09-25 Add complete build project
    [AC_outdoor_unit.stl, Balcony_Screen_BOM.xlsx, Bistro_chair.stl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]
2026-09-25 Cut list names in fusion360 model
